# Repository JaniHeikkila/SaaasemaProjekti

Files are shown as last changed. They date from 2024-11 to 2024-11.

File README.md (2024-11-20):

# SaaasemaProjekti

Tarkoituksena oli tehdä sääasema joka mittaa lämpötilaa, ilmanpainetta, -kosteutta, sademäärää sekä tuulennopeutta. Projekti suunniteltiin ja rakennettiin piirilevyä myöten itse. Projekti onnistui suunnitelmien mukaisesti.

Valmis projekti
ValmisProjekti

Piirilevy

Lohkokaavio

Jänniteregulaattori
Jännite regulaattori

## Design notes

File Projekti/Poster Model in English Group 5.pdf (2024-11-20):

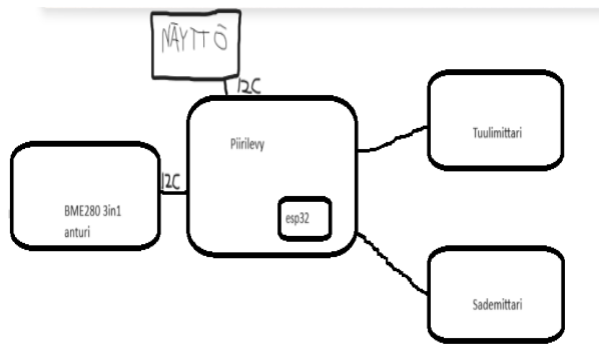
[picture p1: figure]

Electronics Application Project

ECTS Credits: 15

Date of Publication: 2024, Spring

Instructors: Johanna Talvensaari

## Weather station

Tomas Paananen, Taneli Huikari, Jani Heikkilä, TVT22spl Information Technology, Electronics Application Project

Introduction
The purpose of this project was to create a functioning weather station using the ESP32 WROOM 32
microcontroller, displaying weather data on an OLED screen.

Objectives
The objective was to construct a weather station that measures humidity, temperature, atmospheric pressure, rainfall, and wind speed. The station is programmed using Arduino.

FIGURE 1. Block Diagram.

Methods
The microcontroller | used in | the
project | is the ESP32 WROOM 32.
We employed BME280 and HC-SR04 sensors. The BME280
measures temperature, humidity, and
atmospheric pressure. | The HC-SR04
is an ultrasonic | sensor that
measures the water height in the rain gauge. A Hall sensor used in the anemometermeasures the rotational
speed of the blades' | axis. The
connection | is shown in | | figure 1. The
finished | circuit | board | is shown in
figure | | 3. A 12V voltage is supplied | | to
the circuit | board, which is | converted
to suitable | levels | for each | component
by LM7805 and MCP1700x voltage regulators. The LM7805 converts the voltage from 12V to 5V and the MCP1700x from 5V to 3.3V. See
figure | 2. The rain | gauge
automatically empties itself at set intervals or when the container is full.

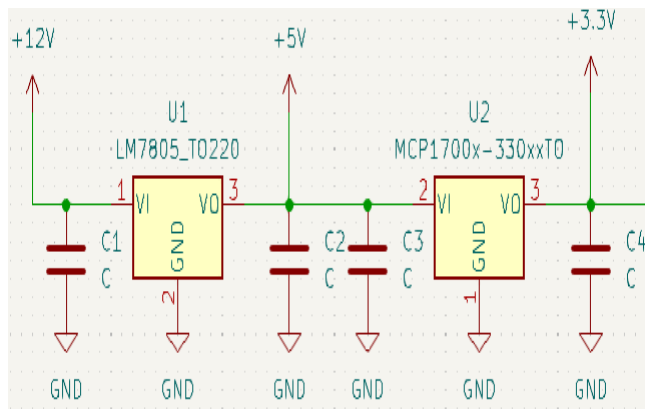
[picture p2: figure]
A magnetic valve is used for the emptying process.

FIGURE 2. Voltage Regulator Assembly.

Results
The weather station functions exactly as we planned. The display shows weather data in real time, with

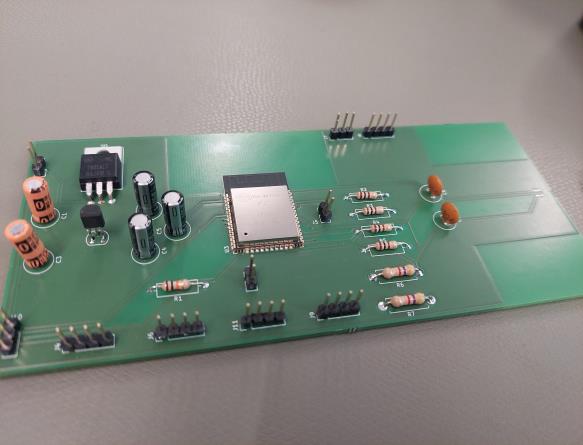
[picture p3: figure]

FIGURE 3. Circuit Board Without Sensors and Display.

Conclusions
In this project, we created a functional weather station that reliably measures weather data. Through careful planning and seamless teamwork, we achieved an excellent outcome. In summary, the project provided valuable learning experiences and demonstrated the potential of school projects in developing technical skills.

References
1.ESP32 WROOM 32 datasheet: https://www.espressif.com/sites/default/files/documentation/esp32-wroom-32_datasheet_en.pdf
2. BME280 datasheet:
https://www.mouser.com/datasheet/2/783/BST-BME280-DS002-
1509607.pdf (https://www.mouser.com/datasheet/2/783/BST-BME280-DS002-1509607.pdf)
3. Hall-sensor datasheet:
https://www.alldatasheet.com/datash eetpdf/pdf/55092/ALLEGRO/A3144.htm l

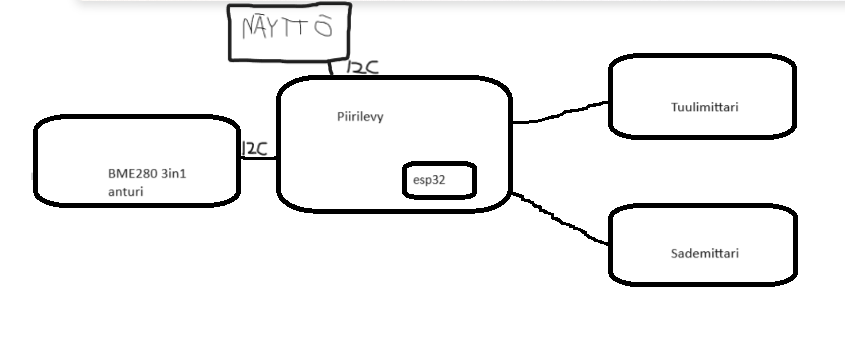
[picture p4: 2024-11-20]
Projekti/Lohkokaavio.png

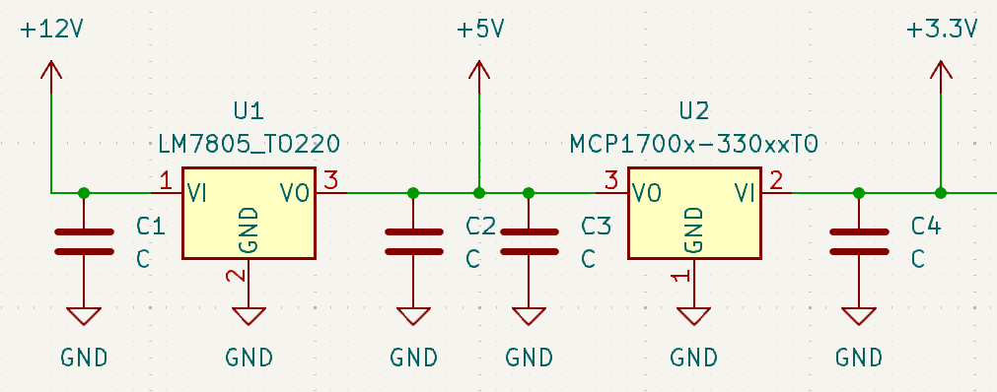
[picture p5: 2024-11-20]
Projekti/Jännite regulaattori.png

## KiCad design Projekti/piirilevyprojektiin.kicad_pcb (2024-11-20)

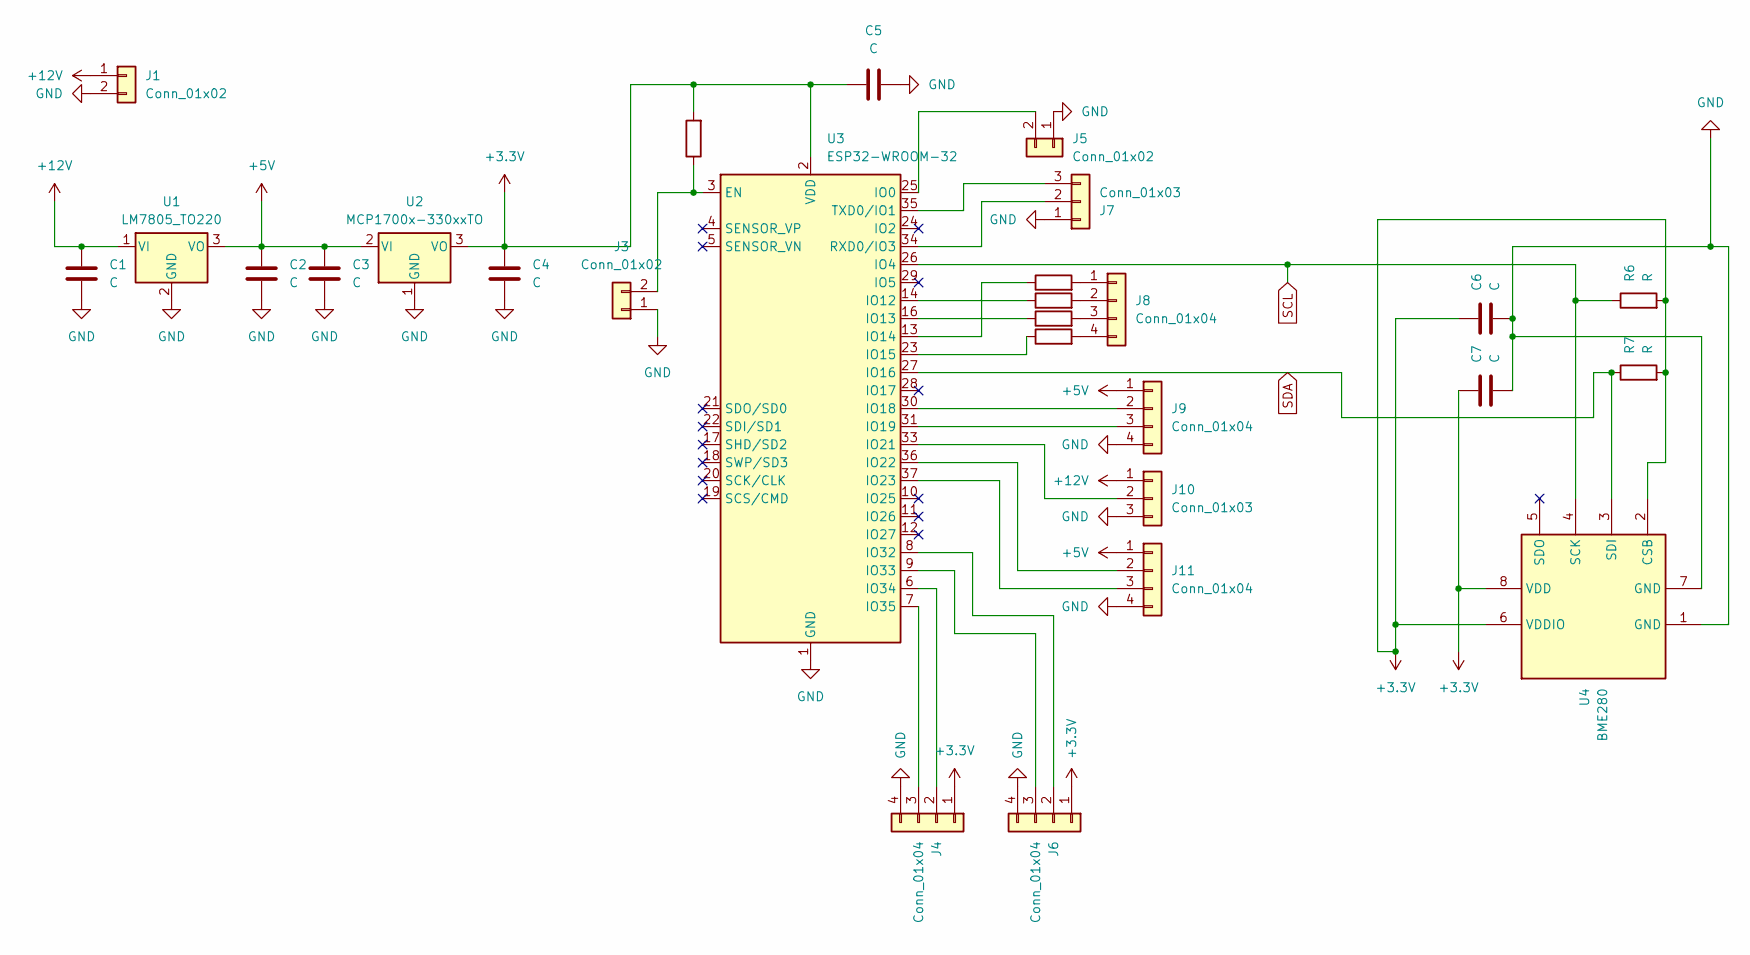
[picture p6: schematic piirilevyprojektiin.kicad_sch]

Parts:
C1, C2, C3, C4, C5, C6, C7: C; C_Radial_D6.3mm_H7.0mm_P2.50mm
J1, J3, J5: Conn_01x02; PinHeader_1x02_P2.54mm_Vertical
J4, J6, J8, J9, J11: Conn_01x04; PinHeader_1x04_P2.54mm_Vertical
J7, J10: Conn_01x03; PinHeader_1x03_P2.54mm_Vertical
R1, R2, R3, R4, R5: R; R_Axial_DIN0309_L9.0mm_D3.2mm_P12.70mm_Horizontal
R6, R7: R; R_Axial_DIN0411_L9.9mm_D3.6mm_P12.70mm_Horizontal
U1: LM7805_TO220; TO-220-3_Horizontal_TabDown
U2: MCP1700x-330xxTO; TO-92L_HandSolder
U3: ESP32-WROOM-32
U4: BME280; Bosch_LGA-8_2.5x2.5mm_P0.65mm_ClockwisePinNumbering

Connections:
+3.3V: C4.1, C5.2, C6.1, C7.1, J4.1, J6.1, R1.2, R6.2, R7.2, U2.3 (VO), U3.2 (VDD), U4.2 (CSB), U4.6 (VDDIO), U4.8 (VDD)
+5V: C2.1, C3.1, J9.1, J11.1, U1.3 (VO), U2.2 (VI)
+12V: C1.1, J1.1, J10.1, U1.1 (VI)
GND: C1.2, C2.2, C3.2, C4.2, C5.1, C6.2, C7.2, J1.2, J3.1, J4.4, J5.1, J6.4, J7.1, J9.4, J10.3, J11.4, U1.2 (GND), U2.1 (GND), U3.1 (GND), U3.15 (GND), U3.38 (GND), U3.39 (GND), U4.1 (GND), U4.7 (GND)
unnamed: J3.2, R1.1, U3.3 (EN)
unnamed: J4.2, U3.6 (IO34)
unnamed: J4.3, U3.7 (IO35)
unnamed: J5.2, U3.25 (IO0)
unnamed: J6.2, U3.8 (IO32)
unnamed: J6.3, U3.9 (IO33)
unnamed: J7.2, U3.34 (RXD0/IO3)
unnamed: J7.3, U3.35 (TXD0/IO1)
unnamed: J8.1, R2.2
unnamed: J8.2, R3.2
unnamed: J8.3, R4.2
unnamed: J8.4, R5.2
unnamed: J9.2, U3.30 (IO18)
unnamed: J9.3, U3.31 (IO19)
unnamed: J10.2, U3.33 (IO21)
unnamed: J11.2, U3.36 (IO22)
unnamed: J11.3, U3.37 (IO23)
unnamed: R3.1, U3.14 (IO12)
unnamed: R4.1, U3.16 (IO13)
unnamed: R2.1, U3.13 (IO14)
unnamed: R5.1, U3.23 (IO15)
SCL: R6.1, U3.26 (IO4), U4.4 (SCK)
SDA: R7.1, U3.27 (IO16), U4.3 (SDI)

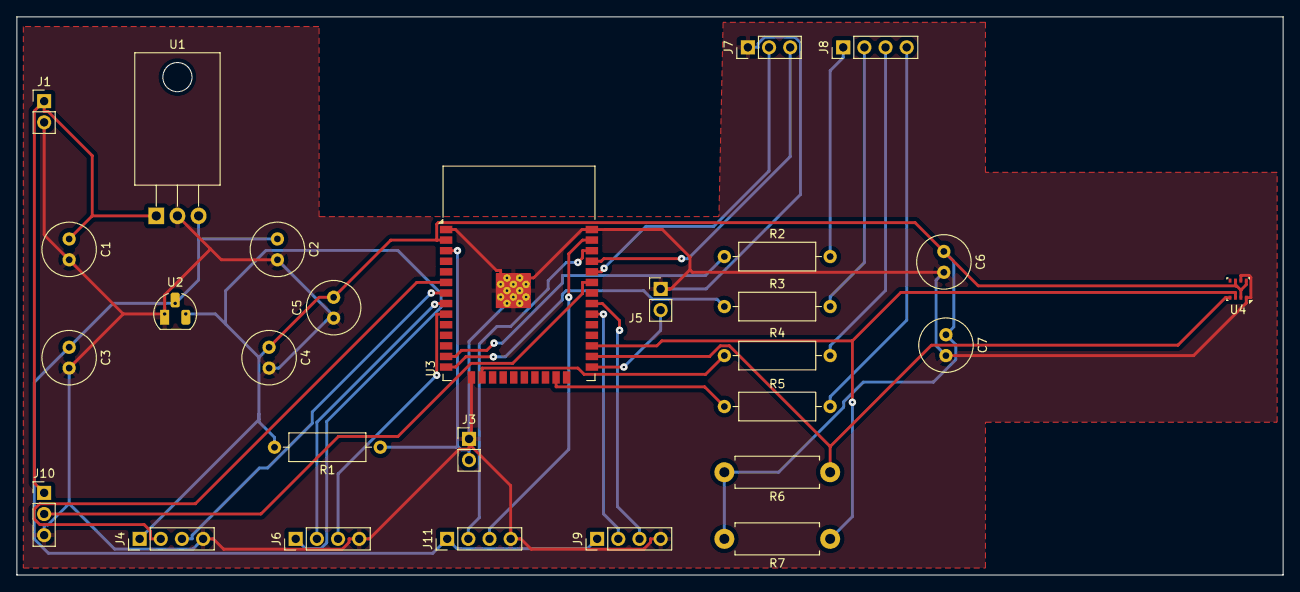
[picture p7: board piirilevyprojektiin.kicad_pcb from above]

Board: 2 copper layers, 152.0 x 67.0 mm, 28 parts (0 on the bottom side), 27 nets.

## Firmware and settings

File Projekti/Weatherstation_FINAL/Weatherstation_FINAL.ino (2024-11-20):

#include <Wire.h>
#include <SPI.h>
#include <Adafruit_Sensor.h>
#include <Adafruit_BME280.h>
#include <Adafruit_GFX.h>
#include <Adafruit_SSD1306.h>
#include <Ticker.h>


#define TRIG_PIN 18
#define ECHO_PIN 19
#define VALVE_PIN 32
Adafruit_BME280 bme; // Temperature, Humidity and pressure sensor
Adafruit_SSD1306 display = Adafruit_SSD1306(128, 32, &Wire); // Oled screen
unsigned long delayTime;


//Rain gauge
float alpha = 0.3;
float filteredDistance = 0;
unsigned long valveTimer = 0;
unsigned long lastMeasurementTime = 0; // Aika viimeisimmästä mittauksesta
unsigned long lastDrainMessageTime = 0; // Aika viimeisimmästä viestistä
bool isDraining = false;
const unsigned long drainDuration = 10000; // 10 seconds
const unsigned long measurementInterval = 500; // Mittausväli millisekunteina

float calibrationDistances[4] = {300, 200, 100, 40}; // mm
float calibrationVolumes[4] = {0, 10, 30, 40}; // ml


//Wind speed sensor
const int Sensor_Pin = 23;
int marker1 = 0;            // Wind speed            
int icounter = 0;           // Interrupt counter for rotation detection
int icounterold = 0;        // Old interrupt counter for rotation detektion
unsigned long counter1;     // Wind spped
float time1;                // Wind speed (time in [ms] for one rotation)
float radius = 0.0816;        // Radius between center and middle of half hemisphere position, meters
float lamda = 0.3;          // Lambda is a constant for amemometer type with 3 hemisphere, lamda = 0,3
float pi = 3.14159265359;   // Pi constant
float windspeed_hz;         
float windspeed_mps;       


Ticker Timer;
 
// Interrupt routine for wind speed
void interruptRoutine1() {
  if(marker1 == 0){
    time1 = float(counter1);
    counter1 = 0;
    marker1 = 1;
    icounter += 1;
  }
  else{
    marker1 = 0;
  }
}

// 1ms counter
void counter() {
  if(marker1 == 1){
    counter1 += 1;
   }
} 

void setup() {
  Serial.begin(115200);
  pinMode(TRIG_PIN, OUTPUT);
  pinMode(ECHO_PIN, INPUT);
  pinMode(VALVE_PIN, OUTPUT);
  digitalWrite(VALVE_PIN, LOW); // Ensure the valve is closed on startup

  pinMode(Sensor_Pin, INPUT_PULLUP);

  display.begin(SSD1306_SWITCHCAPVCC, 0x3C);  // initialize with the I2C addr 0x3C (for the 128x64)
   // init done
  display.display();
  delay(100);
  display.clearDisplay();
  display.display();
  display.setTextSize(1.2);
  display.setTextColor(WHITE);
  
  bool status;
  // default settings
  // (you can also pass in a Wire library object like &Wire2)
  status = bme.begin(0x76);  
  if (!status) {
    Serial.println("Could not find a valid BME280 sensor, check wiring!");
    while (1);
  }

  Serial.println("-- Default Test --");
  delayTime = 1000;

  Serial.println();

  Timer.attach_ms(1, counter);     // Start timer function "counter" each 1ms
  // Start interrupts
  attachInterrupt(Sensor_Pin, interruptRoutine1, FALLING);
}

//RAIN GAUGE
float calculateVolume(float distance) {
  if (distance <= calibrationDistances[3]) {
    return calibrationVolumes[3];
  } else if (distance >= calibrationDistances[0]) {
    return calibrationVolumes[0];
  }
  for (int i = 3; i > 0; i--) {
    if (distance >= calibrationDistances[i] && distance <= calibrationDistances[i-1]) {
      float volumeDifference = calibrationVolumes[i-1] - calibrationVolumes[i];
      float distanceDifference = calibrationDistances[i-1] - calibrationDistances[i];
      float proportion = (distance - calibrationDistances[i]) / distanceDifference;
      return calibrationVolumes[i] + proportion * volumeDifference;
    }
  }
  return 0;
}


void loop() {
  unsigned long currentTime = millis();
  display.setCursor(0,0);
  display.clearDisplay();
  

  //WIND SPEED
  if(time1 == 0.0){
    time1 = 0.0001;
  }

    // Wind speed n[Hz] = 1 / time1[ms] *1000
  windspeed_hz = 1.0 / time1 * 1000;
  // If rotation off then windspeed_hz = 0
  if(icounter == icounterold){
    windspeed_hz = 0.0;
  }
  icounterold = icounter;
  // Wind speed, v[m/s] = (2 * Pi * n[Hz] * r[m]) / lamda[1]
  windspeed_mps = (2 * pi * windspeed_hz * radius) / lamda;


  //RAIN GAUGE
  if (isDraining && currentTime - lastDrainMessageTime >= 1000) {
    int secondsLeft = (drainDuration - (currentTime - valveTimer)) / 1000;
    Serial.print("Drainage in progress... ");
    Serial.print(secondsLeft);
    Serial.println(" seconds remaining.");
    lastDrainMessageTime = currentTime;
  }

  if (currentTime - valveTimer >= drainDuration && isDraining) {
    digitalWrite(VALVE_PIN, LOW);
    Serial.println("Drainage complete.");
    isDraining = false;
  }

  if (currentTime - lastMeasurementTime >= measurementInterval) {
    lastMeasurementTime = currentTime; // Update the last measurement time

    digitalWrite(TRIG_PIN, LOW);
    delayMicroseconds(2);
    digitalWrite(TRIG_PIN, HIGH);
    delayMicroseconds(10);
    digitalWrite(TRIG_PIN, LOW);

    long duration = pulseIn(ECHO_PIN, HIGH);
    float distance_mm = (duration * 0.343) / 2;
    filteredDistance = alpha * distance_mm + (1 - alpha) * filteredDistance;

    float volume_ml = calculateVolume(filteredDistance);

    Serial.print("Distance: ");
    Serial.print(filteredDistance);
    Serial.print(" mm, Volume: ");
    Serial.println(volume_ml);
    

    if (volume_ml >= 40 && !isDraining) {
      digitalWrite(VALVE_PIN, HIGH);
      valveTimer = currentTime;
      isDraining = true;
      lastDrainMessageTime = currentTime - 1000; // Force immediate first messag
    }
  }
  display.print("T:"); display.print(bme.readTemperature()); display.print(" C, ");
  display.print("H:"); display.print(bme.readHumidity()); display.println(" %");
  display.print("P:"); display.print(bme.readPressure() / 100.0F); display.println(" hPa");
  display.print("W:"); display.print(windspeed_mps); display.println("m/s");
  display.print("R:"); display.print(volume_ml); display.println("ml");
    
}

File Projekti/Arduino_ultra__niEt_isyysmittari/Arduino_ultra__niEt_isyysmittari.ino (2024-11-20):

// Määritellään HC-SR04 sensorin pinnit
const int trigPin = 9;
const int echoPin = 10;

// Määritellään muuttujat etäisyydelle ja ajalle
long duration;
int distance;

void setup() {
  // Alustetaan sarjaportti nopeudella 9600 bps
  Serial.begin(9600);

  // Asetetaan trigPin OUTPUT-tilaan ja echoPin INPUT-tilaan
  pinMode(trigPin, OUTPUT);
  pinMode(echoPin, INPUT);
}

void loop() {
  // Lähetetään 10 mikrosekunnin pituinen pulssi trigPinille
  digitalWrite(trigPin, LOW);
  delayMicroseconds(2);
  digitalWrite(trigPin, HIGH);
  delayMicroseconds(10);
  digitalWrite(trigPin, LOW);

  // Luetaan echoPinin tila
  duration = pulseIn(echoPin, HIGH);

  // Lasketaan etäisyys senttimetreinä
  distance = duration * 0.034 * 10 / 2;

  // Tulostetaan etäisyys sarjaporttiin
  Serial.print("Etäisyys: ");
  Serial.print(distance, 1);
  Serial.println(" mm");

  // Pieni viive ennen seuraavaa mittauskierrosta
  delay(1000);
}
